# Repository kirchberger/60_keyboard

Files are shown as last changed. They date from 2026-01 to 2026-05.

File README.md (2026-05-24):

# 60_keyboard

This is the design of a custom keyboard for myself.

Ideas I would perfer for my keyboard:

A keyboard with a small spacebar so that there can be modifiers such as super, alt and ctrl easily assesable with my thumbs. Similar ot a JIS layout.

The keys closer to orthogonal in the second row, since it moves some keys on the right far.

Remove the top row of keys since they are difficult to reach, and I never seem to use them. ESC and delete can be moved down.

Remove the dedicated caps lock key since I never seem to use it.

Then ideally move the []\ keys so that they may be closer.

# Hardware 

Based on ESP32, choosing the least expensive one in the JLPCB library with enough IO and RISC-V core. Choosing ESP32-C6. 

Looking to make a 12x5 matrix for the keys after idea generation, this layout is in the layout_idea folder.

Looking to use standard MX mechanical switch sockets with hot swapable recepticles for potential replacement in the future. 

One usb interface.

Also have a diode on each key so that ghosting is not an issue.

# Overview of the Repo 

PCB is designed in the the PCB folder, the 3D CAD is designed in [OnShape](https://cad.onshape.com/documents/0a169c5ae1023445fae5efdd/w/4e7a7d406d370b73ca30bc79/e/bc0921f5439b5b5204013faf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) with stl files and gcode files for an Ender 3 pro in the 3dcad folder, and the firmware is in the firmware folder.

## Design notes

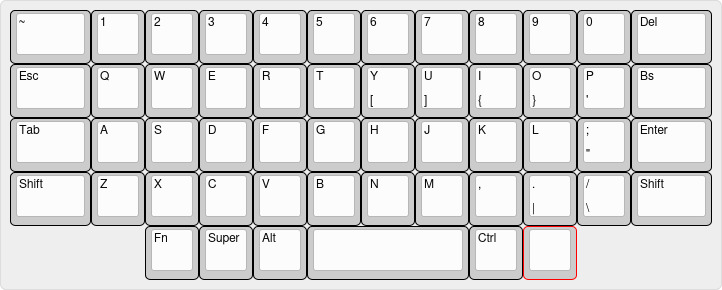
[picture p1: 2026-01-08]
layoutIdea/keyboard-layout.jpg

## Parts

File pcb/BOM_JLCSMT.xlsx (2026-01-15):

Comment | Designator | Footprint | JLCPCB Part #（optional）
1u, 0402 | C8,C12,C13,C5 | C_0402_1005Metric_Pad0.74x0.62mm_HandSolder | C52923
Hot Swap Switch | SW55,SW108,SW107,SW106,SW105,SW104,SW103,SW102,SW101,SW79,SW82,SW68,SW85,SW59,SW86,SW76,SW97,SW99,SW58,SW83,SW100,SW72,SW56,SW93,SW66,SW81,SW92,SW64,SW95,SW94,SW60,SW69,SW63,SW78,SW80,SW96,SW67,SW90,SW70,SW65,SW77,SW89,SW61,SW74,SW57,SW84,SW73,SW87,SW62,SW88,SW75,SW71,SW98,SW91 | Hot_Swap | C41430893
100n, 0402 | C6,C9,C10,C4,C3 | C_0402_1005Metric_Pad0.74x0.62mm_HandSolder | C1525
Diode, SOD-123 | D85,D83,D61,D71,D95,D72,D55,D87,D67,D80,D70,D73,D77,D102,D104,D76,D78,D101,D56,D92,D89,D68,D79,D64,D63,D90,D84,D60,D103,D74,D58,D105,D107,D93,D65,D86,D99,D98,D62,D91,D94,D81,D75,D57,D82,D69,D59,D100,D108,D66,D96,D97,D106,D88 | D_SOD-123 | C81598
10k, 0402 | R6,R5,R4,R3 | R_0402_1005Metric_Pad0.72x0.64mm_HandSolder | C25744
14p, 0402 | C15,C14 | C_0402_1005Metric_Pad0.74x0.62mm_HandSolder | C3037644
TYPE-C-31-M-12 | J1 | USB_C_Receptacle_HRO_TYPE-C-31-M-12 | C165948
22, 0402 | R7,R8 | R_0402_1005Metric_Pad0.72x0.64mm_HandSolder | C25092
5.5V, TVS | D1,D4,D5 | D_SOD-323_HandSoldering
10u, 0402 | C1,C11,C2,C7 | C_0402_1005Metric_Pad0.74x0.62mm_HandSolder | C15525
CAS-120A | SW1 | Nidec_Copal_CAS-120A | C22401620
7M40000049 | Y1 | XTAL_7M40000049 | C337591
GD25Q32ESIGR | U3 | SOIC127P790X216-8N | C2832998
2n, 0402 | L1 | L_0402_1005Metric_Pad0.77x0.64mm_HandSolder | C3032791
XC6220B331MR | U2 | SOT-23-5 | C22466451
ESP32-C6 | U1 | QFN40P500X500X90-41N | C5364646
5.1k, 0402 | R2,R1 | R_0402_1005Metric_Pad0.72x0.64mm_HandSolder | C25905
24n, 0402 | L2 | L_0402_1005Metric_Pad0.77x0.64mm_HandSolder | C74301

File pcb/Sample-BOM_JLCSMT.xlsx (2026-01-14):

Comment | Designator | Footprint | JLCPCB Part #（optional）
100uF | C1 | CAP-SMD_L3.5-W2.8 | C16133
15K | R5,R6 | R0603 | C22809
DC-005-20A_C136744 | DC1 | DC-IN-TH_DC-005-20A | C136744
Header-Female-2.54_1x8 | P2,P3 | HDR-TH_8P-P2.54-V | C27438
K2-1102DP-C4SW-04 | SW1 | KEY-TH_4P-L6.0-W6.0-P4.50-LS6.5 | C110153
ATMEGA328P-PU | U1 | DIP-28_L34.6-W7.3-P2.54-LS10.2-BL | C33901
670688000 | USB1 | USB-B-TH_67068-8000 | C114097

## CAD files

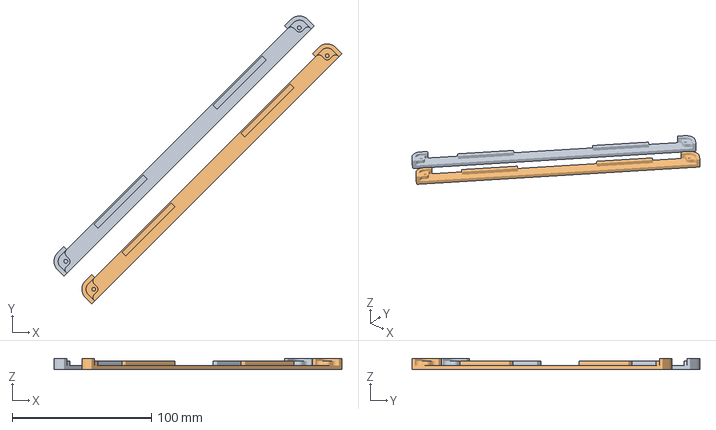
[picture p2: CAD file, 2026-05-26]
3dcad/leg_support.3mf
206.7 x 206.7 x 8.00 mm
leg_support.stl x 2

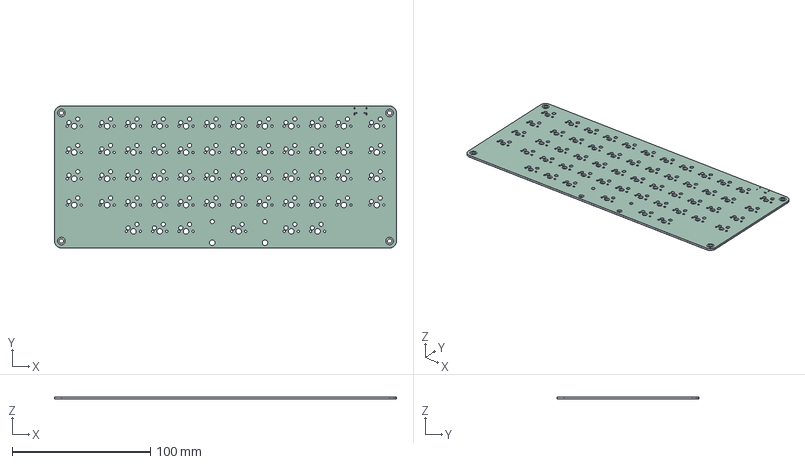
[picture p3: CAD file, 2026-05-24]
3dcad/60_keyboard.step
247.0 x 102.5 x 1.66 mm
60_keyboard_silkscreen x 2
60_keyboard_soldermask x 2
60_keyboard_PCB

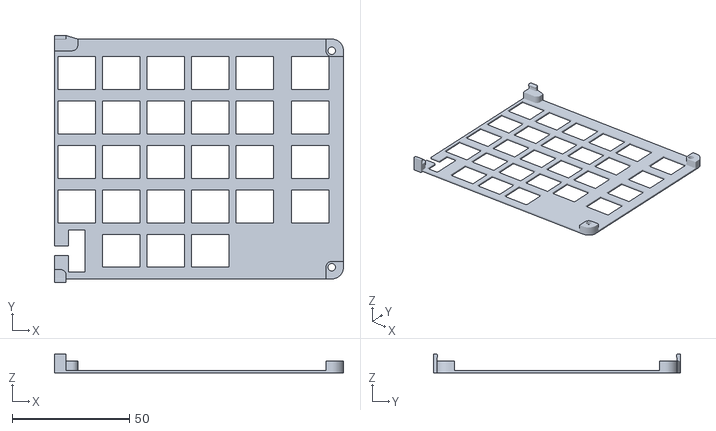
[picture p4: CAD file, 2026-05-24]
3dcad/plate_left.stl
123.5 x 105.5 x 8.00

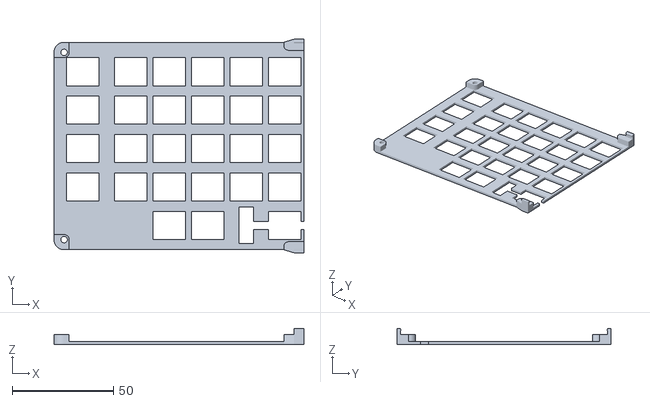
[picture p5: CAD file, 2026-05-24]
3dcad/plate_right.stl
123.5 x 105.5 x 8.00

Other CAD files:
3dcad/leg_support.stl

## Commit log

2026-01-08 starting schematic
    [60_keyboard.kicad_pcb, 60_keyboard.kicad_sch]
2026-01-08 Added main parts
    [60_keyboard.kicad_pcb, 60_keyboard.kicad_sch, matrix.kicad_sch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]
2026-01-09 Finished most of schematic
    [micro.kicad_sch, power.kicad_sch]
2026-01-10 Finished main component selection
    [micro.kicad_sch, power.kicad_sch]
2026-01-11 All Schematic Parts Added
    [60_keyboard.kicad_pcb, micro.kicad_sch, power.kicad_sch]
2026-01-12 Schematic finalized and general layout completed
    [matrix.kicad_sch, micro.kicad_sch, power.kicad_sch]
2026-01-14 Finished board, with maybe some cleanup needed
    [60_keyboard.kicad_pcb, matrix.kicad_sch, micro.kicad_sch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]
2026-01-14 Creeated all fabrication outputs and such, but assembly is expensive when it is both sides. So I will look to fix this.
    [60_keyboard-B_Cu.gbr, 60_keyboard-B_Mask.gbr, 60_keyboard-B_Paste.gbr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]
2026-01-15 board almost finished
    [60_keyboard.kicad_pcb, matrix.kicad_sch]
2026-01-15 Finished board
    [60_keyboard.kicad_pcb]
2026-01-15 Finished for day
    [60_keyboard-B_Cu.gbr, 60_keyboard-B_Mask.gbr, 60_keyboard-B_Paste.gbr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]
2026-01-15 ordered board
    [60_keyboard-B_Cu.gbr, 60_keyboard-B_Mask.gbr, 60_keyboard-B_Paste.gbr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]
2026-05-24 Adding 3D design
    [60_keyboard.step, leg_support.3mf, leg_support.stl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]
2026-05-28 started a couple things
